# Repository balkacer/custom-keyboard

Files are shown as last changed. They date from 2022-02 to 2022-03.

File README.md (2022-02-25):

# Orange Moon Keyboard

This is a custom keyboard for the streamer [blodiemoon](https://www.twitch.tv/blodiemoon).

## Design

Orange Moon Design

## Legends

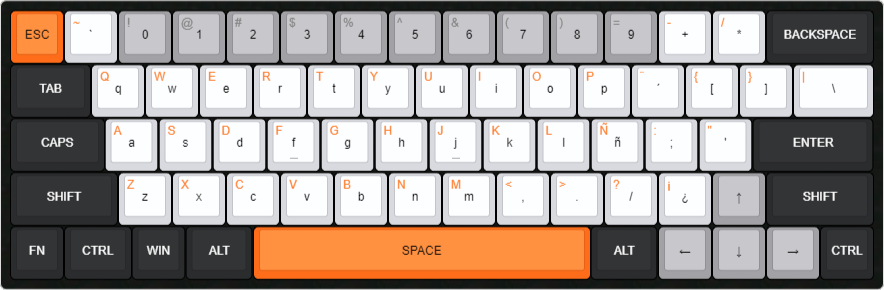
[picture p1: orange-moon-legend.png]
Orange Moon Design


## Plate Layout

Orange Moon Design

## External links

- [Twitch](https://www.twitch.tv/blodiemoon)
- [Keyboard Layout Editor](http://www.keyboard-layout-editor.com/)
- [Auto Hotkey](https://www.autohotkey.com/)

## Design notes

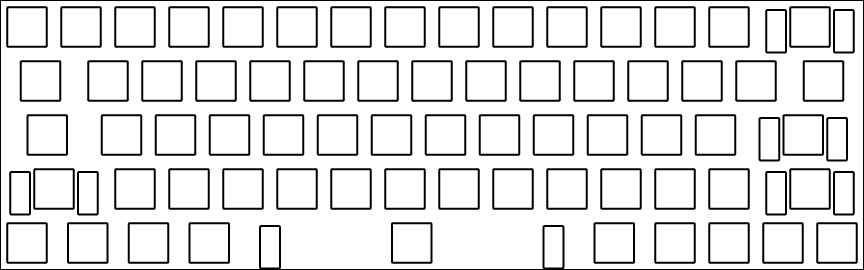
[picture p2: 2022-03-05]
plate.jpg

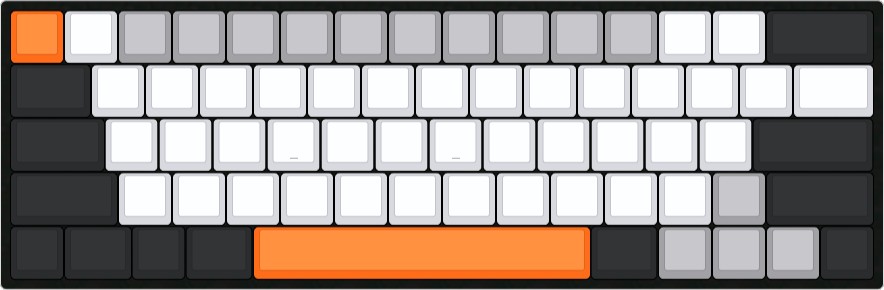
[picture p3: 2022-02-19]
orange-moon.png

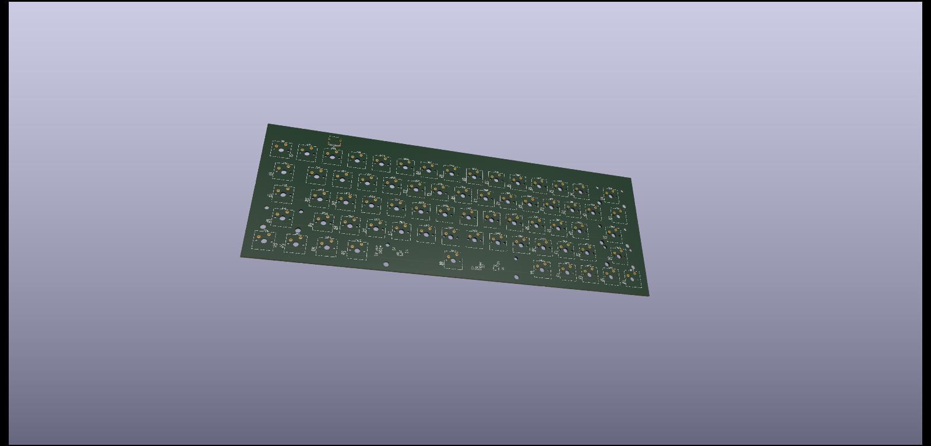
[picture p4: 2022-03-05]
orange-moon/orange-moon.jpg

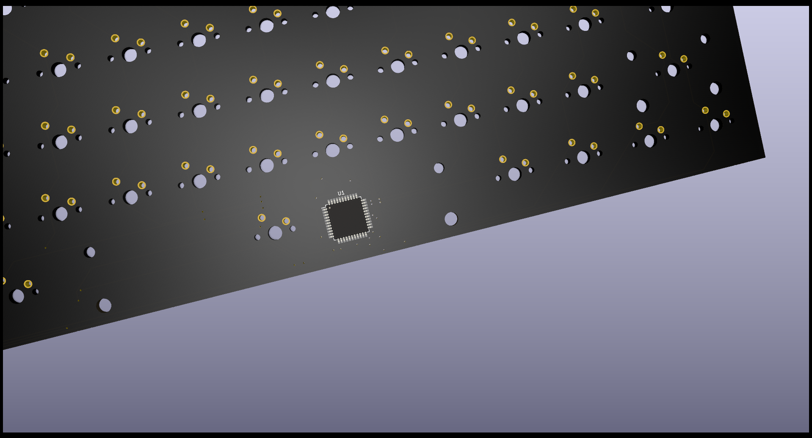
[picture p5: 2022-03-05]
orange-moon/orange-moon.png

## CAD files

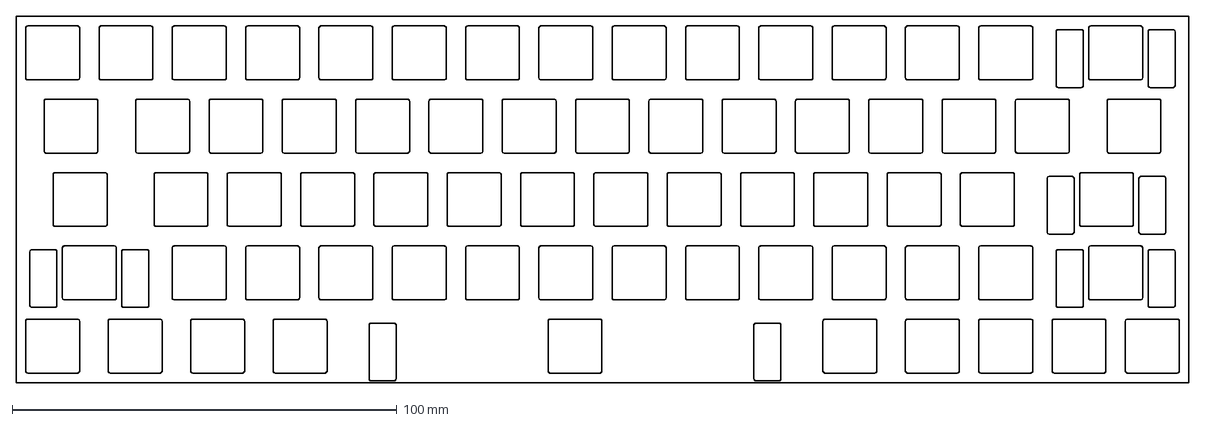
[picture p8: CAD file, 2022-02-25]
plate.dxf
304.8 x 95.2 mm

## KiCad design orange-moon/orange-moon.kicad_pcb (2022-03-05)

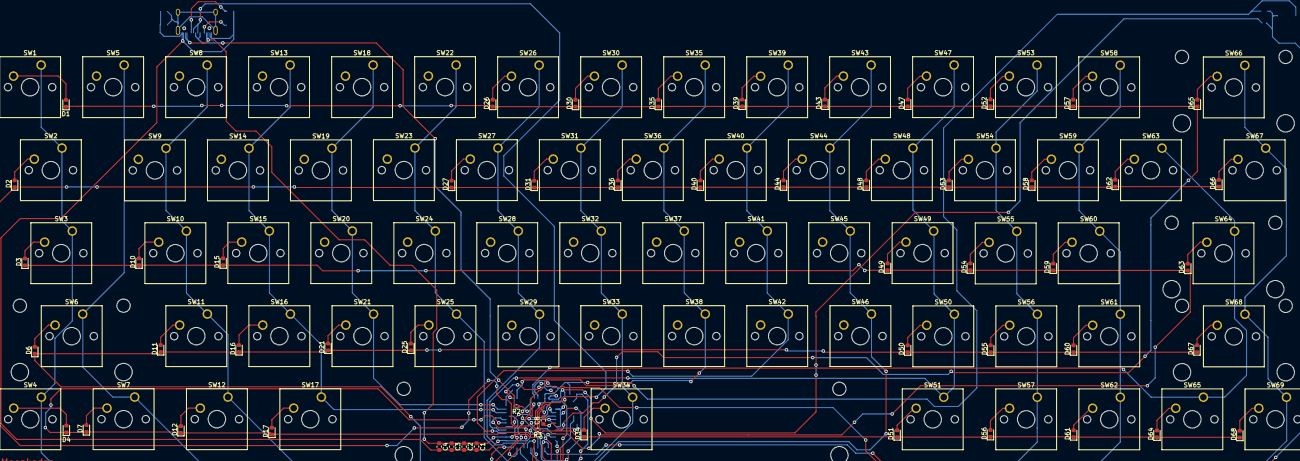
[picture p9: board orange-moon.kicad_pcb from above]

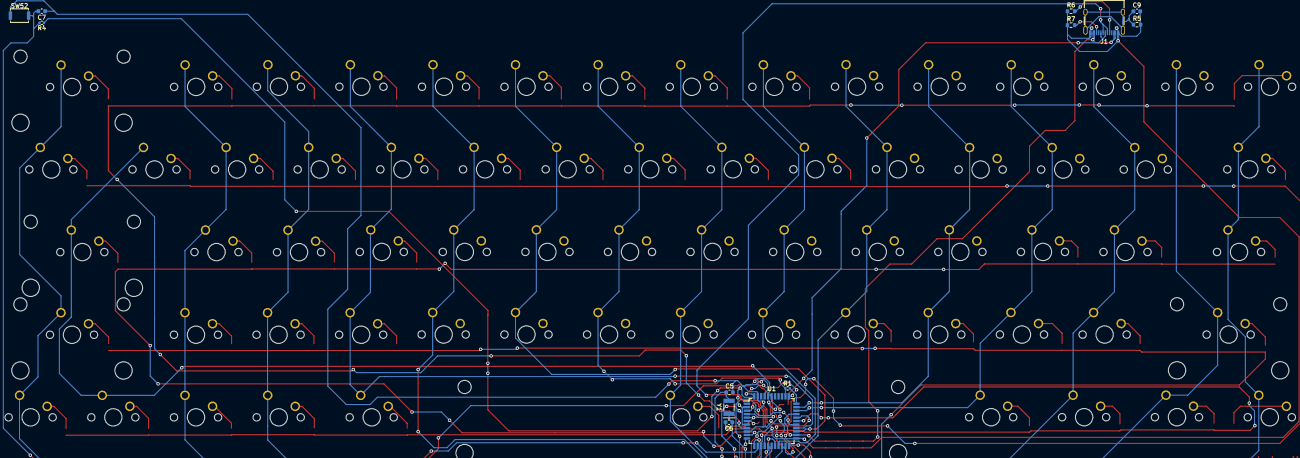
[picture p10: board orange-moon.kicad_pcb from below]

Board: 2 copper layers, 135 parts (13 on the bottom side), 82 nets.

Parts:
C1: 10u; C_0603_1608Metric
C2, C8: 1u; C_0603_1608Metric
C3, C4: 100u; C_0603_1608Metric
C5, C6: 22p; C_0603_1608Metric
C7, C9: 100n; C_0603_1608Metric
D1, D2, D3, D4, D6, D7, D10, D11, D12, D15, D16, D17, D21, D25, D26, D27, D30, D31, D34, D35, D36, D39, D40, D43, D44, D47, D48, D49, D50, D51, D52, D53, D54, D55, D56, D57, D58, D59, D60, D61, D62, D63, D64, D65, D66, D67, D68: D_Small; D_0603_1608Metric
J1: USB_C_Receptacle; USB_C_Receptacle_XKB_U262-16XN-4BVC11
R1, R4: 10k; R_0402_1005Metric
R2, R3: 22; R_0402_1005Metric
R5: 1M; R_0603_1608Metric
R6, R7: 5.1k; R_0603_1608Metric
SW1, SW4, SW5, SW8, SW9, SW10, SW11, SW12, SW13, SW14, SW15, SW16, SW18, SW19, SW20, SW21, SW22, SW23, SW24, SW25, SW26, SW27, SW28, SW29, SW30, SW31, SW32, SW33, SW35, SW36, SW37, SW38, SW39, SW40, SW41, SW42, SW43, SW44, SW45, SW46, SW47, SW48, SW49, SW50, SW53, SW54, SW55, SW56, SW57, SW58, SW59, SW60, SW61, SW62, SW63, SW65, SW69: Mechanical_Switch; SW_Cherry_MX_1.00u_PCB
SW2, SW67: Mechanical_Switch; SW_Cherry_MX_1.50u_PCB
SW3: Mechanical_Switch; SW_Cherry_MX_1.75u_PCB
SW6, SW66, SW68: Mechanical_Switch; SW_Cherry_MX_2.00u_PCB
SW7, SW17, SW51: Mechanical_Switch; SW_Cherry_MX_1.25u_PCB
SW34: Mechanical_Switch; SW_Cherry_MX_6.25u_PCB
SW52: SW_Push; SW_Push_SPST_NO_Alps_SKRK
SW64: Mechanical_Switch; SW_Cherry_MX_2.25u_PCB
U1: ATmega32U4-A; TQFP-44_10x10mm_P0.8mm
Y1: 16MHz; Resonator_SMD_Murata_CDSCB-2Pin_4.5x2.0mm

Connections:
+5V: C1.1, C2.1, C3.1, C4.1, J1.A4 (VBUS), J1.A9 (VBUS), J1.B4 (VBUS), J1.B9 (VBUS), R4.1, U1.2 (UVCC), U1.7 (VBUS), U1.14 (VCC), U1.24 (AVCC), U1.34 (VCC), U1.44 (AVCC)
COL1: SW1.1, SW2.1, SW3.1, SW4.1, U1.29 (PB5)
COL2: SW5.1, SW6.1, SW7.1, U1.30 (PB6)
COL3: SW8.1, SW9.1, SW10.1, SW11.1, SW12.1, U1.12 (PB7)
COL4: SW13.1, SW14.1, SW15.1, SW16.1, SW17.1, U1.31 (PC6)
COL5: SW18.1, SW19.1, SW20.1, SW21.1, U1.32 (PC7)
COL6: SW22.1, SW23.1, SW24.1, SW25.1, U1.18 (PD0)
COL7: SW26.1, SW27.1, SW28.1, SW29.1, U1.19 (PD1)
COL8: SW30.1, SW31.1, SW32.1, SW33.1, SW34.1, U1.20 (PD2)
COL9: SW35.1, SW36.1, SW37.1, SW38.1, U1.21 (PD3)
COL10: SW39.1, SW40.1, SW41.1, SW42.1, U1.25 (PD4)
COL11: SW43.1, SW44.1, SW45.1, SW46.1, U1.22 (PD5)
COL12: SW47.1, SW48.1, SW49.1, SW50.1, SW51.1, U1.26 (PD6)
COL13: SW53.1, SW54.1, SW55.1, SW56.1, SW57.1, U1.27 (PD7)
COL14: SW58.1, SW59.1, SW60.1, SW61.1, SW62.1, U1.41 (PF0)
COL15: SW63.1, SW64.1, SW65.1, U1.40 (PF1)
COL16: SW66.1, SW67.1, SW68.1, SW69.1, U1.39 (PF4)
GND: C1.2, C2.2, C3.2, C4.2, C5.2, C6.2, C7.1, C8.2, C9.2, J1.A1 (GND), J1.A12 (GND), J1.B1 (GND), J1.B12 (GND), R1.1, R5.2, R6.1, R7.1, SW52.1, U1.5 (UGND), U1.15 (GND), U1.23 (GND), U1.35 (GND), U1.43 (GND)
unnamed: C5.1, U1.17 (XTAL1), Y1.2
unnamed: C6.1, U1.16 (XTAL2), Y1.1
unnamed: C8.1, U1.6 (UCAP)
unnamed: C9.1, J1.S1 (SHIELD), R5.1
unnamed: D1.2 (A), SW1.2
unnamed: D2.2 (A), SW2.2
unnamed: D3.2 (A), SW3.2
unnamed: D4.2 (A), SW4.2
unnamed: D6.2 (A), SW6.2
unnamed: D7.2 (A), SW7.2
unnamed: D10.2 (A), SW10.2
unnamed: D11.2 (A), SW11.2
unnamed: D12.2 (A), SW12.2
unnamed: D15.2 (A), SW15.2
unnamed: D16.2 (A), SW16.2
unnamed: D21.2 (A), SW21.2
unnamed: D25.2 (A), SW25.2
unnamed: D27.2 (A), SW27.2
unnamed: D31.2 (A), SW31.2
unnamed: D34.2 (A), SW34.2
unnamed: D35.2 (A), SW35.2
unnamed: D36.2 (A), SW36.2
unnamed: D39.2 (A), SW39.2
unnamed: D40.2 (A), SW40.2
unnamed: D43.2 (A), SW43.2
unnamed: D49.2 (A), SW49.2
unnamed: D50.2 (A), SW50.2
unnamed: D51.2 (A), SW51.2
unnamed: D56.2 (A), SW57.2
unnamed: D57.2 (A), SW58.2
unnamed: D58.2 (A), SW59.2
unnamed: D59.2 (A), SW60.2
unnamed: D61.2 (A), SW62.2
unnamed: D62.2 (A), SW63.2
unnamed: D64.2 (A), SW65.2
unnamed: D65.2 (A), SW66.2
unnamed: D66.2 (A), SW67.2
unnamed: D67.2 (A), SW68.2
unnamed: R1.2, U1.33 (~HWB/PE2)
unnamed: R2.1, U1.4 (D+)
unnamed: R3.1, U1.3 (D-)
unnamed: J1.A5 (CC1), R6.2
unnamed: J1.B5 (CC2), R7.2
unnamed: D17.2 (A), SW17.2
unnamed: D26.2 (A), SW26.2
unnamed: D30.2 (A), SW30.2
unnamed: D44.2 (A), SW44.2
unnamed: D47.2 (A), SW47.2
unnamed: D48.2 (A), SW48.2
unnamed: D52.2 (A), SW53.2
unnamed: D53.2 (A), SW54.2
unnamed: D54.2 (A), SW55.2
unnamed: D55.2 (A), SW56.2
unnamed: D60.2 (A), SW61.2
unnamed: D63.2 (A), SW64.2
unnamed: D68.2 (A), SW69.2
ROW1: D1.1 (K), D26.1 (K), D30.1 (K), D35.1 (K), D39.1 (K), D43.1 (K), D47.1 (K), D52.1 (K), D57.1 (K), D65.1 (K), U1.8 (PB0)
ROW2: D2.1 (K), D27.1 (K), D31.1 (K), D36.1 (K), D40.1 (K), D44.1 (K), D48.1 (K), D53.1 (K), D58.1 (K), D62.1 (K), D66.1 (K), U1.9 (PB1)
ROW3: D3.1 (K), D10.1 (K), D15.1 (K), D49.1 (K), D54.1 (K), D59.1 (K), D63.1 (K), U1.10 (PB2)
ROW4: D6.1 (K), D11.1 (K), D16.1 (K), D21.1 (K), D25.1 (K), D50.1 (K), D55.1 (K), D60.1 (K), D67.1 (K), U1.11 (PB3)
ROW5: D4.1 (K), D7.1 (K), D12.1 (K), D17.1 (K), D34.1 (K), D51.1 (K), D56.1 (K), D61.1 (K), D64.1 (K), D68.1 (K), U1.28 (PB4)
RST: C7.2, R4.2, SW52.2, U1.13 (~RESET)
USB_DN: J1.A7 (D-), J1.B7 (D-), R3.2
USB_DP: J1.A6 (D+), J1.B6 (D+), R2.2

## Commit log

2022-02-25 KiCad project
    [orange_moon.kicad_pcb, orange_moon.kicad_sch]
2022-02-25 Upload plate layout
    [plate.dxf]
2022-02-25 Adding plate layout to readme
2022-03-05 Adding new kicad project
    [orange-moon.kicad_pcb, orange-moon.kicad_sch, orange_moon.kicad_pcb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]
